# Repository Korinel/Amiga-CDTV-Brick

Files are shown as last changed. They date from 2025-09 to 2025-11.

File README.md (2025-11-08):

# The Commodore CDTV Brick 
## Two-player IR joystick interface

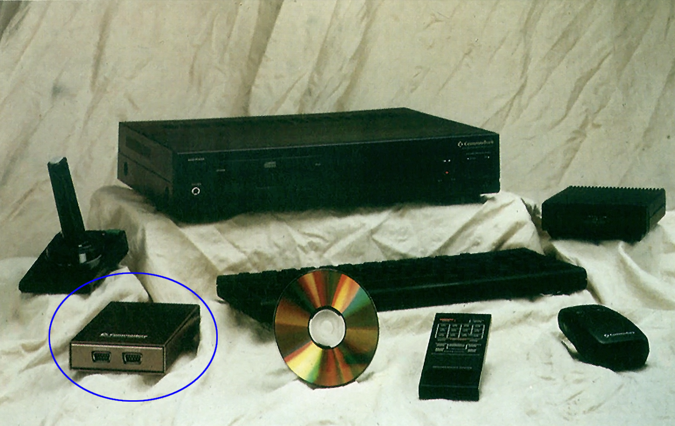
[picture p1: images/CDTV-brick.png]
Brick from CES

*The original Brick*

The circled **Commodore CDTV Brick** was a 1990s CDTV input device that sadly never made it to retail shelves. Instead, it appears that its functionality was integrated into the **Commodore CDTV CD1200** (below). The design of this Brick is entirely based on reverse engineering the protocols from the **CD1200 Trackball**, **CD1252/CD1253 mice**, **Brickette**, and the **CDTV Remote**.

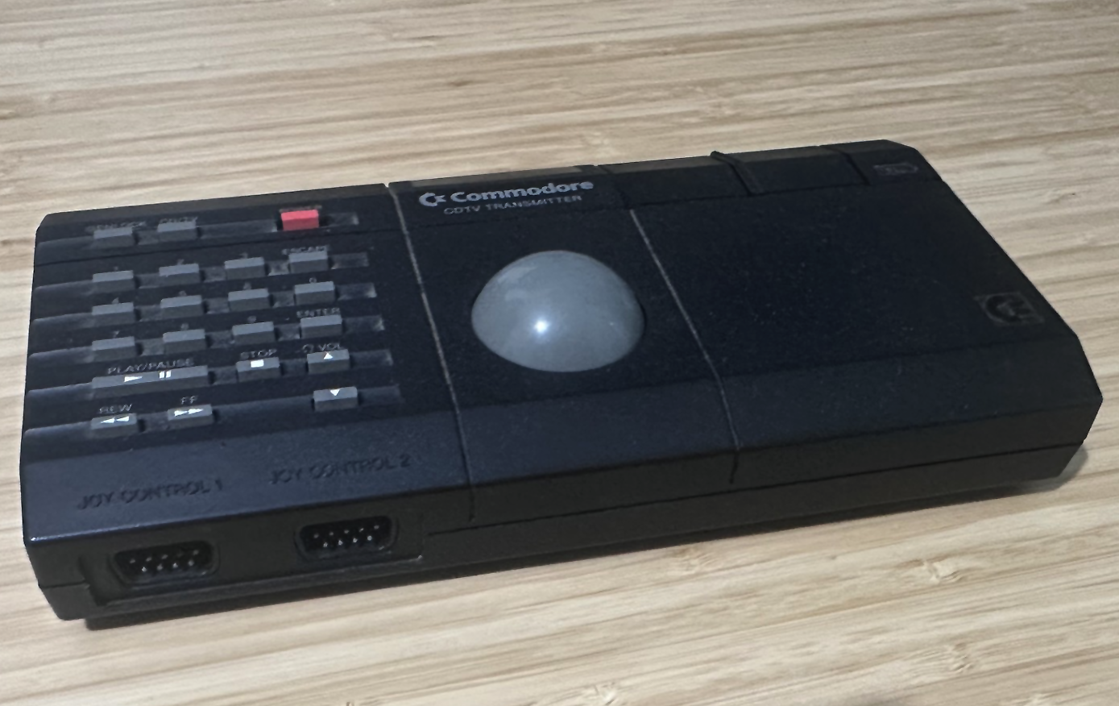
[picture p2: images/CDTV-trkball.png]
CD1200

*The CD1200, obtain via a mortgage!!*

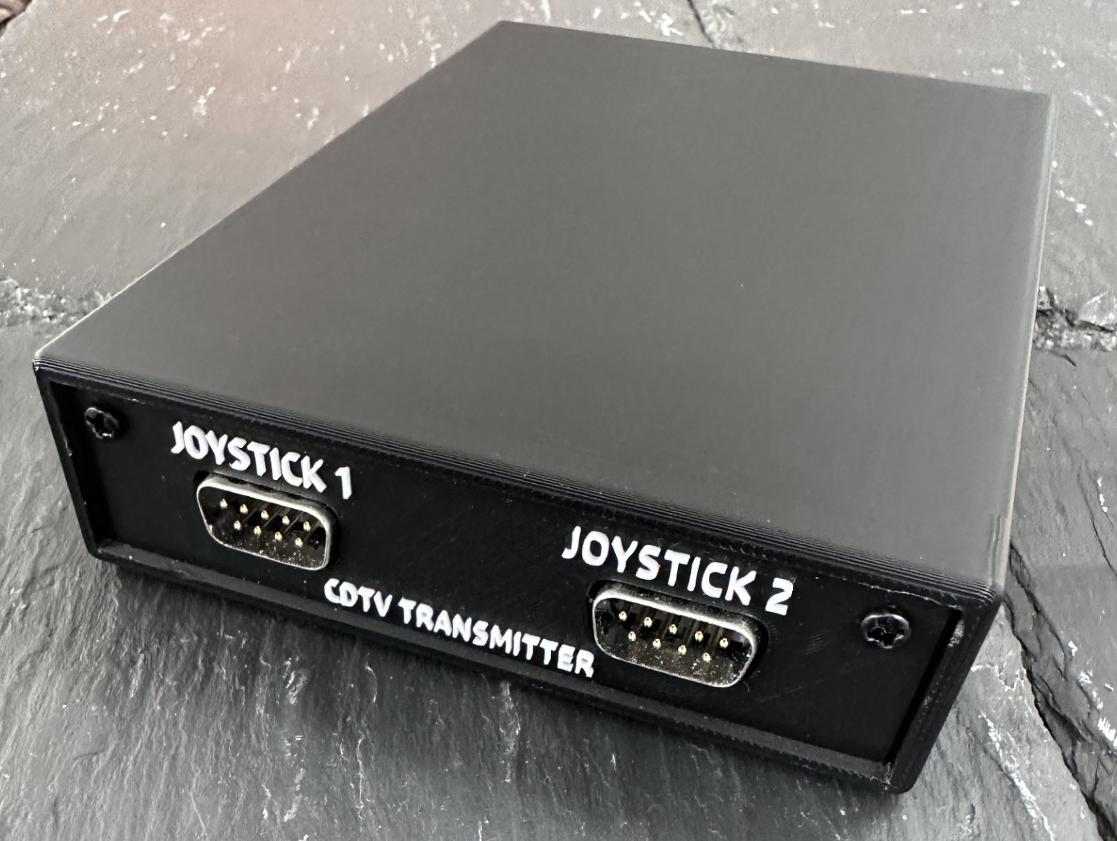
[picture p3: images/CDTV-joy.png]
CDTV Setup

*The Prototype Brick!*

## Project Overview
This  purpose of this project is to help makers design and build new devices, as the original retro mice, remote and trackerball command heavy prices second hand so there is an eager market for cheaper alternatives, without these input devices the CDTVs I fear will end up in landfill! 

The Pico project simply takes joystick input over GPIO, converts it to the IR protocol, and transmits it to an IR LED via a MOSFET. The code in this repro is for the Raspberry Pi Pico, both the RP2040 or newer RP2350 work fine. Visual Studio Code and the Offical Raspberry Pi Pico Extension were used to build the code. Everything is vanilla so should be easy enough to compile. The implementation is intentionally minimal for clarity, to enable ports to other MCUs, but there are known limitations:

1. **PWM vs PIO**: It may be preferable to use Pico PIO, as demonstrated in the [Pico IR example](https://github.com/raspberrypi/pico-examples/blob/master/pio/ir_nec/README.adoc).
2. **No defensive programming**: There is no error handling or debug output—failures may go unnoticed.
3. **Battery conservation**: No power-saving measures are implemented. The device does not stop timers or reduce CPU/PWM load during inactivity.

## Results!

The Brick performs exceptionally well, it enables **wireless two-player simultaneous Amiga gameplay**, testing on titles such as *Battle Squadron*, *SWIV*, *Project X*, *Zool*, and *Superfrog*—all played well without noticeable lag. More importantly, it avoids the need to open up the CDTV, remove chips, or pay upwards of **$1000 for a CD1200 Trackball**.

## Building Your Own

### PCB Manufacturing
The `KiCad` folder contains gerber files ready for PCB fabrication. Send these to your preferred manufacturer (JLCPCB, PCBWay, etc.), or use the schematic to build your own, the circuit is simple enough to prototype on a breadboard.

### 3D Printed Enclosure
3MF/STL files for the housing and faceplate are in the `3DPrint` folder. They're also available on [MakerWorld](https://makerworld.com/en/models/1804520-commodore-cdtv-2-joystick-ir-transmitter-enclosure).

### Firmware Installation
1. Install VSCode with the official Raspberry Pi Pico extension
2. Clone this repository
3. Build the project using the Pico SDK
4. Flash to your Pico via either:
   - USB mass storage mode (drag and drop the .uf2 file)
   - Debug probe using SWD pins

Good luck!

## Joystick Protocol

The joystick protocol appears to be *undocumented!* but here is the specification for use in your own devices:

- **Carrier frequency**: 40 kHz  
- **Duty cycle**: 33%

### Signal Encoding

Both mouse and joystick protocols use the same bit encoding:

| Bit | Mark (µs) | Space (µs) | Total (µs) |
|-----|---|---|---|
| 0 | 150 | 725 | 875 |
| 1 | 500 | 375 | 875 |

> All timing values should divide evenly by 25.

### Joystick Frame Structure

- **Header**: `1100` mark followed by `375` µs space  
- **Payload**: 25 bits total   
  - `1` flag for joystick (0 = joystick, 1 = mouse)  
  - `12` bits for two joystick inputs: (P1) F2, F1, R, L, D, U, (P2) F2, F1, R, L, D, U  
  - `12` bits for the inverse of the above, acting as a primitive check bit  
- **Footer**: `800` µs space (no specific footer signal)  
- **Frame duration**: ~24,150 µs (≈41 frames per second)  
- **Transitions per frame**: 52

When the user stops using the joystick, **four consecutive frames of all zeros** are sent. After that, the device ceases transmission, as there's little point repeatedly telling the CDTV that nothing is being pressed. This behaviour matches the CD1200 functionality.

## Brickette Protocol Comparison

The **Brickette** was a wired device similar to the CD1200 using a nearly identical joystick protocol with longer timings:

- **Header**: 1400 µs mark followed by 500 µs space  
- **Bit encoding**:

| Bit | Mark (µs) | Space (µs) | Total (µs) |
|-----|---|---|---|
| 0 | 150 | 1000 | 1150 |
| 1 | 650 | 500 | 1150 |

- **Frame duration**: ~32,000 µs (≈31 frames per second)

The Brickette is approximately **25% more latent** than the CD1200. This is likely because it transmits at the slower clock rate required for mouse support, which also operates at 31 frames per second. The Brickette also does **not** send the four “end of transmission” frames, leaving the CDTV unaware when the user stopped pressing joystick directions. This behaviour can be observed in **Amiga Test Kit**.

## Acknowledgements

This project was inspired by the excellent research and historical insights shared on [CDTV Land](https://cdtvland.com/2021/03/07/cdtv-brick-prototype/) regarding the elusive CDTV Brick prototype. 

---

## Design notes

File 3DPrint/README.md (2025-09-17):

# CDTV IR Transmitter – 3D-Printable Enclosure

This repository contains the 3D print files for the custom enclosure used in my **Commodore CDTV Dual-Joystick IR Transmitter** project.  
The design houses a Raspberry Pi Pico-based PCB, a 3×AA battery pack, dual DE-9 joystick connectors, and an IR LED driver.

You can also find it on MakerWorld https://makerworld.com/en/models/1804520-commodore-cdtv-2-joystick-ir-transmitter-enclosure

The original 1991 Brick design reminded me of an Amiga floppy drive, so I matched its general dimensions and appearance. This provided ample space for the components and added a satisfying heft.

---
Front panel with labelled joystick ports |

## Overview

The case was modelled in Fusion 360 and printed on a Bambu Lab P1S using PLA.  
It provides a snug, screw-together housing for the full PCB assembly, keeping the batteries secure while giving the DE-9 joystick ports a clean, retro look.

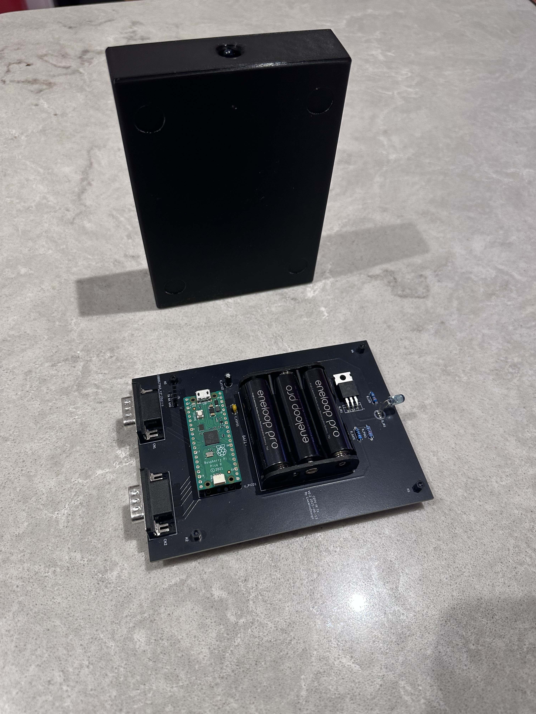
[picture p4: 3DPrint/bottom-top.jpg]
PCB with cover removed
 

# Bare Board Option
If you’d rather keep the board bare, you can simply fit nylon hex standoffs (sometimes called threaded spacers or PCB pillars) into the four mounting holes. These lightweight supports lift the PCB a few millimetres off the surface, preventing the solder joints or header pins from scratching furniture or shorting against anything conductive. Nylon is ideal because it’s non-conductive and won’t mark the desk, but brass or aluminium standoffs can also be used if you need extra rigidity. Just screw them in or use snap-fit pillars and the board will stay safely elevated without a full enclosure.

---

## Files Included

| File | Purpose |
|---|---|
| **CDTV-IR-Transmitter.step** | Full parametric CAD model for editing in Fusion 360, FreeCAD, or any STEP-compatible CAD package. |
| **CDTV-IR-Transmitter.3mf** | Ready-to-print Bambu Studio (3MF) project with recommended orientation and print settings. |
| **top-front.png** | Render/photo of the finished enclosure showing the labelled front panel. |
| **bottom-top.jpg** | Photo of the internal PCB and battery layout for reference. |
| **README.md** | This document. |

You can also download these files on [MakerWorld](https://makerworld.com/en/models/1804520-commodore-cdtv-2-joystick-ir-transmitter-enclosure).

---

## Printing Notes
- **Material:** PLA or PETG  
- **Layer Height:** 0.2 mm  
- **Infill:** 20% grid (or your preferred setting)  
- **Supports:** Not required if printed as supplied  
- **Fasteners:** 2 × M3×8 mm machine screws (for use with the optional heat-set inserts)

The STEP file allows easy editing if you wish to resize the case or change connector cut-outs.

---

## Assembly

1. Solder and fully test the PCB before assembly.  
2. Gently bend the IR LED so it aligns with the case opening, and—if needed—tilt the MOSFET for clearance.  
3. Slide the board along the internal runners, ensuring the IR LED sits correctly in the front hole and points straight ahead.  
4. (Optional) Heat-set two threaded inserts into the base mounting holes for a stronger screw joint.  
5. Fit the front face-plate and guide the DE-9 connectors neatly through their cut-outs.  
6. Attach the face plate, securing it with two screws to match your inserts.

---

## Possible Improvements
1. Add a side cut-out for USB (power) access to the Pico.  
   *Note: the Pico’s central placement makes convenient cable routing awkward.*  
2. Design a more robust power-switch mount.  
   *Bear in mind that extra holes or external switches may compromise the case’s clean look.*  
3. Refine the faceplate fit for easier removal so battery replacement is easier.  
   *It’s currently very snug and can stay in place without screws, but you need to tug the joysticks to remove it.*

Enjoy building your own CDTV IR Transmitter enclosure and feel free to remix or adapt the design!

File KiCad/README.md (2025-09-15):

# 📖 Electronics Design for the CDTV IR Joystick Controller

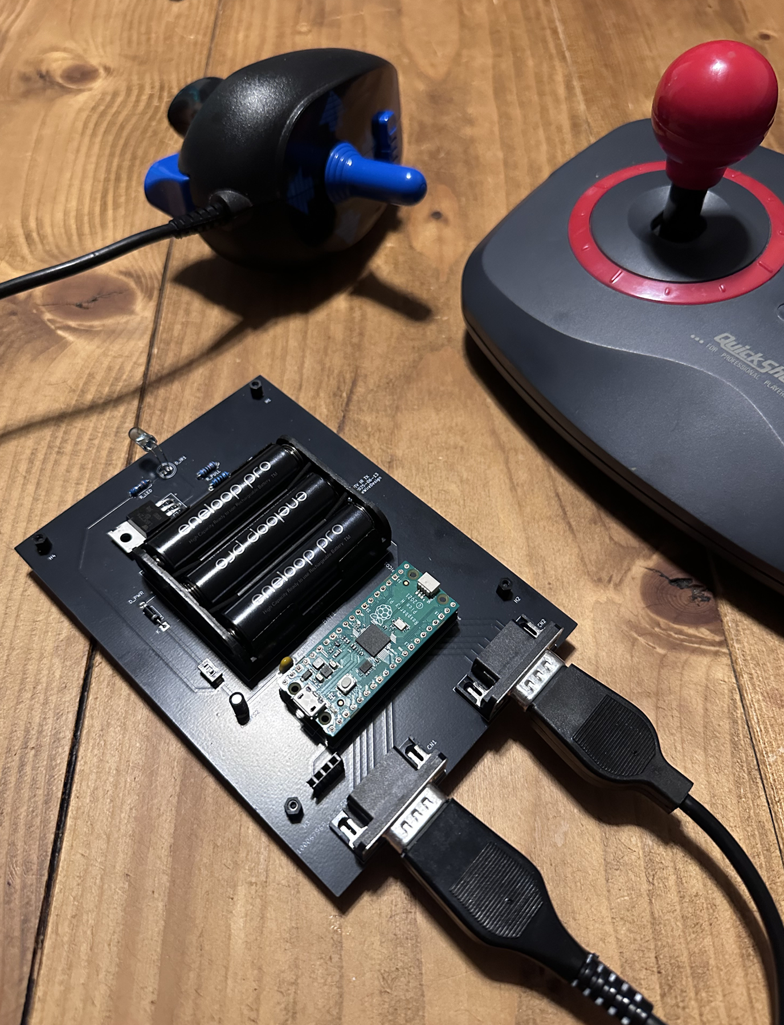
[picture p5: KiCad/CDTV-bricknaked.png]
CDTV IR Controller Schematic


> **N.B.** I am *not* an electrical engineer — I’m a software/reverse engineer by trade.  
> This project is a learning exercise, so there may be mistakes or sub-optimal choices.  
> The design was developed with the help of my good friend ChatGPT 🙂  

This README describes the **electronics design** for a modern replacement of the **Commodore CDTV infrared controllers**.  
It focuses on the hardware built around a **Raspberry Pi Pico (RP2040 or RP2350)** microcontroller, which reads two standard DE-9 joysticks and transmits their states to the CDTV via an **infrared LED driver circuit**.  

The README is organised into three main sections:  

- **🎮 Joystick Circuit** – how the DE-9 ports connect to the Pico, and why they are joystick-only.  
- **🔋 Power Circuit** – how batteries, diodes, and capacitors provide stable power for the Pico and LED.  
- **📡 IR LED Circuit** – how the MOSFET, resistors, and LED generate the CDTV-compatible IR output.  

Additional sections provide:  
- Technical notes on why mice cannot be used with these DE-9 connectors.  
- An overview of the **Amiga/CDTV mouse protocol** for reference.  
- Trade-offs between resistor values and LED current output for builders who want to tune brightness vs. battery life.  

👷 **Who is this for?**  
This README is written for **builders and electronics hobbyists** who want to reproduce, understand, or modify the CDTV IR controller hardware.  
It explains not just *what components are used*, but also *why they are there*, with calculations, alternatives, and practical design trade-offs.

---

## 🧰 Why Through-Hole Components?

This design deliberately uses **through-hole (THT) components** rather than surface-mount (SMD). 

The unit needs to be a little **heavy and bulky** so it doesn’t get dragged around by the joystick cables during frantic gameplay, helping it retain line-of-sight to the CDTV’s IR receiver. 

### Reasons for Through-Hole
- **Large mechanical parts**:  
  - The **battery holder**, **IR LED**, and **DE-9 joystick connectors** are inherently large and designed as through-hole parts.  
  - The **Raspberry Pi Pico module** itself is also a through-hole DIP board.  
  - These parts set the minimum size of the PCB — it will never be a tiny design.  
- **Ease of assembly**:  
  - Through-hole parts are much easier to solder by hand, making this build accessible to hobbyists with basic tools.  
  - Component orientation is clear, and mechanical strength is higher for connectors and switches that will see stress.  
- **Component availability**:  
  - THT resistors, diodes, capacitors, and headers are cheap and widely available.  
  - Builders can source them from almost any electronics supplier or salvage them from donor boards.  

### Could this be SMD?
Swapping to SMD would reduce board size **only for the passives** (resistors, capacitors, pull-ups).  
However:  
- **Battery holders, LEDs, DE-9 connectors, and the Pico** remain large and through-hole.  
- The actual PCB reduction would be modest because the layout must still accommodate these large footprints.  
- SMD would complicate soldering for beginners and make the design harder to reproduce at home.  

---

## 📐 Schematic

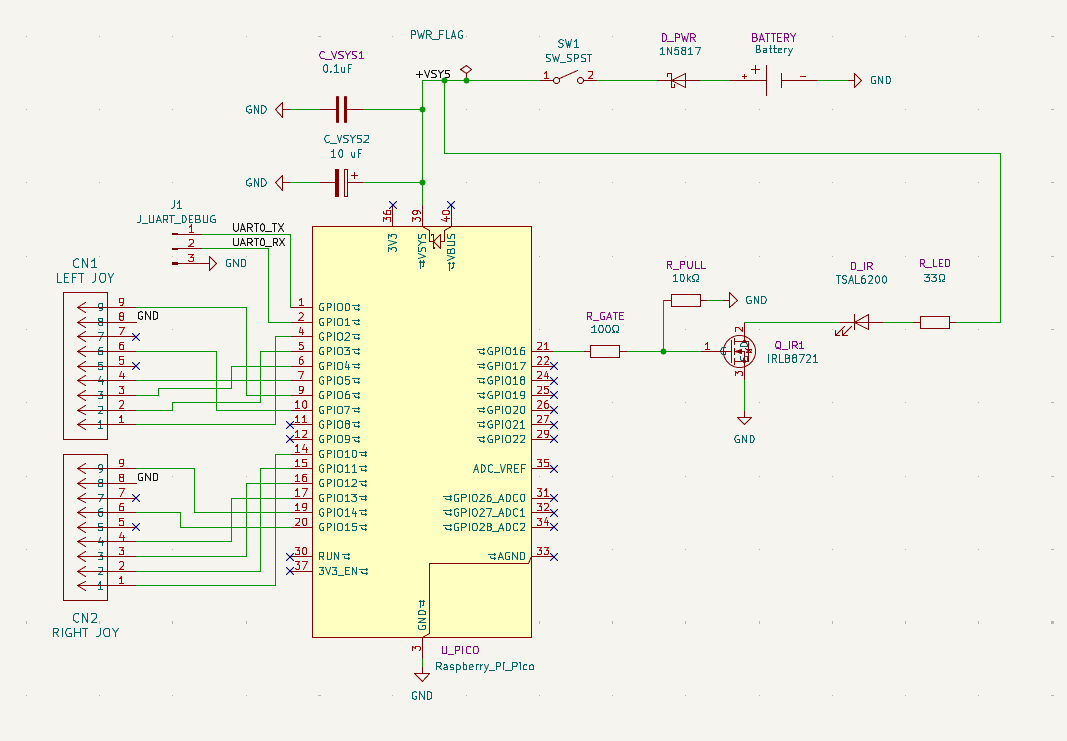
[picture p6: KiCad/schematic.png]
CDTV IR Controller Schematic


---

## 🎮 Joystick Circuit

All joystick ground pins (CN1/CN2), battery negative, and Pico GND must share the same reference. VSYS after the Schottky diode is the main supply rail for both the Pico and the IR LED driver circuit.

| Component | Purpose in Design | Reason | Alternative Options |
|---|---|---|---|
| **U_PICO1 Raspberry Pi Pico** | Main microcontroller (RP2040 or RP2350) that reads joystick inputs and encodes them for IR transmission. All joystick lines are pulled to GND when active, and read as logic LOW by the Pico. VSYS powers the board and sets the logic level reference. | Cheap, widely available, powerful enough for real-time IR modulation. Plenty of GPIO pins for two DE-9 ports. | Arduino Nano/Pro Mini (requires redesign for I/O mapping), STM32 “Blue Pill”. |
| **CN1 / CN2 (DE-9 connectors)** | Standard joystick connectors (Atari/Amiga compatible). Each pin corresponds to joystick direction or fire buttons. Internally wired to Pico GPIO, with common GND pins tied to system GND. **Pin 5 (potentiometer X)** and **Pin 7 (+5 V supply)** are unused. | DE-9 is the Amiga standard, ensures physical compatibility. Right-angle THT sockets are robust for repeated plug/unplug cycles. | Any through-hole DE-9 connector (straight or right-angle). Panel-mount DE-9 with short wires for mechanical flexibility. |

### Notes on Unused Pins
- **Pin 5 (Pot X / analogue input)** – On the original Amiga this is used for analogue paddles or light pens. This design is digital-only, so the pin is left unconnected.  
- **Pin 7 (+5 V supply)** – Provides +5 V to mice and other powered peripherals. Since this board does not support mice and is battery-powered, +5 V is not provided to avoid backfeeding or damaging the Pico.  

### DE-9 Joystick Pinout (per port)

| DE-9 Pin | Function | Pico GPIO |
|---|---|---|
| 1 | Up | GP2 / GP10 |
| 2 | Down | GP3 / GP11 |
| 3 | Left | GP4 / GP12 |
| 4 | Right | GP5 / GP13 |
| 6 | Fire 1 | GP7 / GP15 |
| 9 | Fire 2 | GP6 / GP14 |
| 8 | GND | GND |
| 5, 7 | NC/+5V | Not used |

### ⚠️ Autofire

Autofire is unreliable here (as it was on the original CD1200). Classic autofire works with a direct digital connection and is powered from +5 V on Pin 7.  In this design the Pico must clock and convert joystick inputs into a serial IR stream, so the rapid autofire pulses cannot be transmitted reliably.

---

## 🔋 Power Circuit

All joystick ground pins (CN1/CN2), battery negative, and Pico GND must share the same reference. VSYS after the Schottky diode is the main supply rail for both the Pico and the IR LED driver circuit.

| Component | Purpose in Design | Reason| Alternative Options |
|---|---|---|---|
| **BAT1 (Battery holder)** | Provides portable AA battery supply | 3 × AA is the Pico’s standard input range (VSYS). Delivers ~3.6 V with NiMH and ~4.5 V with Alkaline. After the Schottky diode drop this becomes ~3.25 V (NiMH) or ~4.15 V (Alkaline), which is ideal for the IR LED drive calculations. | Li-ion 18650 3.7 V cell with protection + charging circuit (but requires regulator for safe Pico supply). |
| **D_PWR1 1N5817 (Schottky diode)** | Reverse-current protection and source OR-ing between USB and battery. Prevents backfeeding into the batteries when USB is plugged in. | Very low forward drop (0.2–0.4 V), preserving as much voltage as possible for the LED. Rated for >1 A, so well above the 100 mA load. | 1N5819 (slightly higher drop), SS14 (SMD equivalent). |
| **C_VSYS1 0.1 µF ceramic capacitor** | Local high-frequency decoupling at the Pico VSYS pin. Suppresses fast transients from the IR LED switching and keeps supply stable at the microsecond scale. | Small MLCCs have very low ESR and respond quickly. This value is a “standard bypass” close to the IC. | 0.47 µF or 1 µF ceramic (improves HF filtering further). |
| **C_VSYS2 10 µF electrolytic capacitor** | Bulk smoothing capacitor. Handles lower-frequency voltage dips caused by the IR LED pulsing at 40 kHz. | 10 µF provides enough charge reservoir to stop Pico resets during bursts. Electrolytic tolerates ripple current better than ceramic alone. | 22 µF or 47 µF for longer battery leads or higher burst currents. |
| **SW1 SPST switch** | Physical battery isolation. Breaks connection between the pack and the diode, allowing complete shutdown without USB unplugging. | Slide switches are compact, tactile, and easy to panel-mount. Current rating is comfortably above draw. | Rocker switch (more robust), latching push-button. |

---

## 📡 IR LED Circuit

The IR LED is driven at 40 kHz with a duty cycle <50%, so the average current is well below the peak. This allows safe operation even when instantaneous current approaches the LED’s maximum continuous rating.

| Component | Purpose in Design | Reason | Alternative Options |
|---|---|---|---|
| **D_IR1 TSAL6200 IR LED** | The main emitter. A high-power 940 nm IR LED that converts current pulses into IR light detectable by the CDTV receiver. Forward voltage ~1.35 V at 100 mA, with a 200 mA peak rating. | Wide angle (±20°), high radiant intensity, and spectral match to standard IR demodulators. Handles short current bursts without thermal runaway. | TSAL4400 (narrower 10° beam, longer range), SFH4546 (high-power emitter). |
| **Q_IR1 IRLB8721 (MOSFET)** | Low-side switch for the LED. Takes PWM drive from the Pico and switches LED current through R_LED1. Its low Rds(on) (<20 mΩ) ensures almost no voltage drop, so current is defined by the resistor not the MOSFET. | Logic-level gate threshold (<2 V), meaning it fully enhances with Pico’s 3.3 V output. Robust current handling (tens of amps), way above the sub-0.1 A required here. | IRLZ34N (similar spec, slightly higher Rds(on)), AO3400 (SMD, low gate charge). |
| **R_LED1 33 Ω resistor** | Series current-limiting resistor. Ensures the LED does not exceed its safe forward current by dropping the excess supply voltage. At ~4.15 V (alkaline supply after Schottky drop), current ≈ (4.15 V − 1.35 V)/33 Ω ≈ 85 mA. | Provides reliable current limiting independent of battery type. Keeps LED near 100 mA continuous spec but well under 200 mA pulsed limit. Dissipation ≈ 0.24 W at full current, so a 0.25 W or 0.5 W resistor is appropriate. | 27 Ω (≈100 mA, brighter but hotter), 39 Ω (≈70 mA, dimmer but saves battery). |
| **R_PULL1 10 kΩ** | Gate pull-down resistor. Holds MOSFET gate at 0 V when Pico GPIO is in reset, boot, or high-impedance state. Without it, the gate capacitance could float high and partially turn on the MOSFET, causing LED ghost flicker. | 10 kΩ provides a defined low with negligible current draw from the Pico. Value is not critical—just needs to bleed off gate charge slowly. | 4.7 kΩ (stronger pull-down, faster discharge), 22 kΩ (weaker pull, less leakage). |
| **R_GATE1 100 Ω resistor** | Gate series resistor. Sits between Pico GPIO and MOSFET gate to limit instantaneous charging/discharging current into the gate capacitance (~1 nF). Prevents ringing, reduces EMI, and protects the GPIO driver. | 100 Ω gives a good compromise: Pico can still switch gate fast enough for 40 kHz IR PWM, but without dumping tens of mA into the GPIO pin. | 68 Ω (faster switching, slightly more stress), 220 Ω (slower switching, lower stress). |

## 🔢 IR LED Resistor Trade-offs

| Resistor | Supply | I_LED (mA) | P_R (mW) | P_LED (mW) |
|---|---|---|---|---|
| 27 Ω | Alkaline | 103.7 | 290.4 | 140.0 |
| 27 Ω | NiMH | 70.4 | 133.7 | 95.0 |
| 33 Ω | Alkaline | 84.8 | 237.6 | 114.5 |
| 33 Ω | NiMH | 57.6 | 109.4 | 77.7 |
| 39 Ω | Alkaline | 71.8 | 201.0 | 96.9 |
| 39 Ω | NiMH | 48.7 | 92.6 | 65.8 |

---

## 🛠️ Debug / Programming Header

| Component | Purpose in Design | Reason | Alternative Options |
|---|---|---|---|
| **J1 (3-pin header)** | Breaks out the Pico’s UART for debugging or programming. | Provides a serial console during development, useful for logging joystick states or IR timing. Simple 3-pin header keeps it compact. | Any 3-pin 2.54 mm header. Could also break out full SWD (3 or 5-pin) for low-level debugging. |

### Pinout (J1)
| Pin | Signal | Notes |
|-----|---|---|
| 1 | GND | Common ground reference |
| 2 | TX | Pico TX (connect to RX of USB–UART adapter) |
| 3 | RX | Pico RX (connect to TX of USB–UART adapter) |

⚠️ **Note for builders**:  
- This header is optional if you only intend to flash `.uf2` files via USB.  
- It is strongly recommended during early development or troubleshooting IR timings.  
- Keep the ground pin connected whenever using an external UART adapter to avoid floating reference issues.

---

## 🖱️ Amiga / CDTV Mouse Protocol (and why it is not supported here)

It is important to understand that although Amiga/CDTV joysticks and mice share the same DE-9 connector format, the **signals and requirements are completely different**.

- A **joystick** is just a set of switches. Each direction or fire button shorts its pin to GND when pressed. The Pico can read these directly as active-low digital inputs.  
- An **Amiga mouse** is not switch-based. It uses two quadrature encoders that continuously generate pulse trains on the direction pins as the ball moves. These need to be sampled and decoded in real time.  
- The mouse also expects a **+5 V supply** on Pin 7 of the DE-9 to power its encoders. This design deliberately does not supply 5 V, because it is joystick-only.

### Important clarification  
The **Commodore CD1200 trackball** (the inspiration for this project) also **did not present mouse signals** on its DE-9 ports. Those pins were never wired for mouse use. Instead:  
- The **trackball** in the CD1200 produced its own data stream.  
- That stream used a variation of the **CDTV IR mouse protocol** (serial, not quadrature).  
- Mouse support in the CDTV therefore came from the **dedicated IR mouse (CD-1252) and wired mouse (CD-1253)**, not from the DE-9 joystick sockets.  

### Why mice are not supported here (YET!)
This project replicates the CD1200’s joystick behaviour, not the IR mouse. Supporting mice would require:  
- Supplying +5 V on Pin 7.  
- Capturing and decoding quadrature pulses at high speed.  
- Translating movement into the CDTV’s proprietary IR mouse serial protocol.  

Since the original CD1200 never offered mouse inputs on its DE-9 ports, this design remains **joystick-only** — just like the original hardware.

---

## 📡 CDTV Mouse Serial Protocol

For builders who want to experiment with adding mouse support, here are the key details of the **CDTV mouse protocol** (used by CD-1252 IR and CD-1253 wired mice):

The CDTV mouse (CD-1252 IR / CD-1253 wired) uses a proprietary asynchronous serial protocol.  

- **Frame structure**:  
  - **Start bit**: 1100 µs low pulse, 375 µs high.  
  - **19 data bits**: transmitted MSB first.  
  - **Stop bit**: 100 µs line held low.  

- **Bit encoding** (each bit = ~875 µs total):  
  - **0** = ~500 µs low, ~375 µs high.  
  - **1** = ~150 µs low, ~725 µs high.  

- **Contents of the 19 data bits**:  
  - **Mouse flag** (always `1` to indicate mouse device).  
  - **Button states**: `left` and `right` button down/up.  
  - **X movement**: `8` bit signed value.  
  - **Y movement**: `8` bit signed value.  

- **Timing**:  
  - Packets sent every ~32 ms while the mouse is moving.  
  - There is a ~14 ms gap between frames.  
  - Idle state is a steady HIGH level.  

---
## 🔚 Next Steps

With the electronics design understood, builders can:

1. **Assemble the PCB** – start with resistors and small passives, then add connectors, the Pico, and finally the battery holder and IR LED.  
2. **Build your image** – see the `root` directory for Pico source code.  
3. **Test the IR output** – confirm joystick presses translate into IR frames using a Amiga Test Kit or an oscilloscope.  
4. **Enclose the build** – use the provided 3D-printed case files to house the PCB, ensuring the IR LED has clear line-of-sight to the CDTV receiver.  

This README covers the **hardware design**. For the **firmware details**, please refer to the dedicated firmware documentation in the directory above.

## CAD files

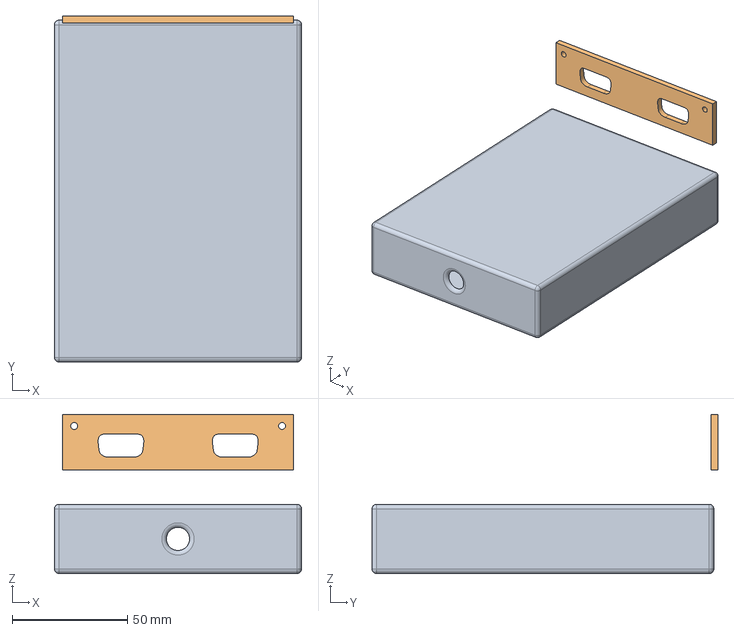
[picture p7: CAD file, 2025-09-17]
3DPrint/CDTV-IR-Transmitter.step
107.0 x 149.8 x 68.9 mm

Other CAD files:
3DPrint/CDTV-IR-Transmitter.3mf

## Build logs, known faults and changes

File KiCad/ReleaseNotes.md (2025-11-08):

# CDTV IR Controller - Release Notes

## Version 0.3
**Release Date:** [2025-11-08]

### Bug Fixes
- **Critical Fix: IR LED Polarity Correction**
  - Corrected IR LED (TSAL6200) orientation in both KiCad schematic symbol and PCB footprint
  - The LED symbol was incorrectly drawn with anode and cathode reversed, causing the component to be installed backwards
  - PCB now matches the TSAL6200 datasheet pinout (Pin 1 = Cathode, Pin 2 = Anode)
  - **Impact:** Previous versions (v0.1 and v0.2) required the IR LED to be installed with reversed polarity to function correctly. Version 0.3 allows correct installation following component markings (flat edge = cathode)

### Acknowledgements
Special thanks to **chrisblown** and **youenchene** for identifying and reporting this critical polarity issue! 

---

## Version 0.2
**Release Date:** [2025-07-18]

### Features Added
- **SW1 Power Switch:** Added a power switch to save on battery power
- **Pico Debug Header:** Exposed TX, RX, and GND pins on Raspberry Pi Pico for serial debugging and programming access

---

## Version 0.1
**Release Date:** [2025-05-15]

### Initial Release
- Original CDTV IR Controller design
- Raspberry Pi Pico-based IR transmitter
- TSAL6200 IR LED with IRLB8721 MOSFET driver circuit
- Basic power management circuitry

---

## Migration Notes

### Upgrading from v0.1 or v0.2 to v0.3
If you have already built a board using v0.1 or v0.2 gerbers:
- Your board will continue to work with the IR LED installed in reverse (opposite to component markings)
- No hardware modifications are required for existing boards
- Future builds using v0.3 gerbers should install the LED following standard component markings (flat edge toward MOSFET)

### Assembly Notes for v0.3
- Install TSAL6200 IR LED with the **flat edge of the dome toward the MOSFET** (cathode side)
- The square pad connects to the cathode (flat edge side)
- The round pad connects to the anode (round edge side)

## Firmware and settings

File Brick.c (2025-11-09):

// =============================================================================
/*
 * Brick - CDTV Joystick to IR Transmitter
 * Copyright (c) 2025 Korinel
 * SPDX-License-Identifier: MIT
 */
// =============================================================================

#include "pico/stdlib.h"     // gpio, sleep_ms, stdio_init_all, panic
#include "pico/time.h"       // repeating_timer_t, add_repeating_timer_us
#include "hardware/clocks.h" // clock_get_hz, clk_sys
#include "hardware/pwm.h"    // pwm APIs
#include "hardware/sync.h"   // __wfi()
#include <stdint.h>          // fixed-width integer types

// =============================================================================
// GPIO Pin Definitions
// =============================================================================

// GPIO Input Pin Definitions (Active LOW inputs)
#define JOY1_UP 2
#define JOY1_DOWN 3
#define JOY1_LEFT 4
#define JOY1_RIGHT 5
#define JOY1_FIRE2 6
#define JOY1_FIRE1 7

#define JOY2_UP 10
#define JOY2_DOWN 11
#define JOY2_LEFT 12
#define JOY2_RIGHT 13
#define JOY2_FIRE2 14
#define JOY2_FIRE1 15

// GPIO Output Pin Definitions (Active HIGH outputs)
#define LED_IR 16
#define LED_PICO 25

// =============================================================================
// IR Protocol Definitions
// =============================================================================

static const uint32_t ir_frequency_hz = 40000;          // 40 kHz carrier = 25us period
static const uint8_t ir_duty_cycle_percent = 33;        // 33% duty (CD1252 mouse is 33% too)
static const uint16_t data_mask = 0x0FFF;               // 12 bits valid data

/* CDTV IR joystick protocol timings (microseconds) */
static const uint32_t ir_hdr_mark_us = 1100;            // 44 * 25us
static const uint32_t ir_hdr_space_us = 375;            // 15 * 25us
static const uint32_t ir_zero_mark_us = 150;            //  6 * 25us
static const uint32_t ir_zero_space_us = 725;           // 29 * 25us
static const uint32_t ir_one_mark_us = 500;             // 20 * 25us
static const uint32_t ir_one_space_us = 375;            // 15 * 25us                
static const uint32_t ir_interframe_gap_us = 800;       // 32 * 25us

// =============================================================================
// GPIO and state definitions
// =============================================================================
// Read joystick GPIO pins in CDTV defined order
static const uint8_t gpio_pins[] = {
    JOY2_UP, JOY2_DOWN, JOY2_LEFT, JOY2_RIGHT, JOY2_FIRE1, JOY2_FIRE2,
    JOY1_UP, JOY1_DOWN, JOY1_LEFT, JOY1_RIGHT, JOY1_FIRE1, JOY1_FIRE2
   };

static const size_t num_gpio_pins = sizeof(gpio_pins) / sizeof(gpio_pins[0]);

// PWM state
static uint32_t pwm_slice_num = 0;
static uint32_t pwm_channel = 0;
static uint16_t pwm_level = 0;

// ISR / timer state
static volatile bool frame_pending = false; // set by timer IRQ, cleared in main loop
static const uint32_t max_idle_frames = 4;  // consecutive idle frames 
static uint32_t idle_frame_count = 0;       // counts consecutive idle frames

// Frame length in microseconds = ~24150 us
static const uint64_t ir_frame_period_us =
    (int64_t)ir_hdr_mark_us + ir_hdr_space_us +
    (13LL * (ir_zero_mark_us + ir_zero_space_us)) +
    (12LL * (ir_one_mark_us + ir_one_space_us)) +
    ir_interframe_gap_us;

static repeating_timer_t frame_timer; // frame timer handle

// =============================================================================
// Initialization
// =============================================================================
static void init_gpio(void)
{
    // Configure joystick inputs as pulled-up (active LOW)
    for (size_t i = 0; i < num_gpio_pins; ++i)
    {
        int pin = gpio_pins[i];
        gpio_init(pin);
        gpio_set_dir(pin, GPIO_IN);
        gpio_pull_up(pin);
    }

    // Configure LED for feedback
    gpio_init(LED_PICO);
    gpio_set_dir(LED_PICO, GPIO_OUT);
    gpio_put(LED_PICO, 0);
}

static void init_pwm_for_ir(void)
{
    // configure pin for PWM and capture slice/channel
    gpio_set_function(LED_IR, GPIO_FUNC_PWM);
    pwm_slice_num = pwm_gpio_to_slice_num(LED_IR);
    pwm_channel = pwm_gpio_to_channel(LED_IR);

    // compute wrap (ticks per carrier period) and duty in ticks
    uint32_t sys_clk_freq = clock_get_hz(clk_sys);

    uint16_t pwm_wrap = (uint16_t)((sys_clk_freq / (ir_frequency_hz)) - 1);
    pwm_level = (pwm_wrap * ir_duty_cycle_percent) / 100; // IR_DUTY_CYCLE is the percentage

    // initialise PWM with required wrap and start it, keep output off
    pwm_config config = pwm_get_default_config();
    pwm_config_set_wrap(&config, pwm_wrap);

    pwm_init(pwm_slice_num, &config, true);
    pwm_set_chan_level(pwm_slice_num, pwm_channel, 0);
}

// =============================================================================
// IR transmission logic
// =============================================================================
static inline void ir_emit(uint32_t mark_us, uint32_t space_us)
{
    // Turn carrier on for mark_us then off for space_us using PWM level
    pwm_set_chan_level(pwm_slice_num, pwm_channel, pwm_level);
    busy_wait_us_32(mark_us);

    pwm_set_chan_level(pwm_slice_num, pwm_channel, 0);
    busy_wait_us_32(space_us);
}

static void transmit_cdtv_frame(uint16_t joy_data)
{
    // Ensure only the lower 12 bits are used
    uint16_t check_bits = (uint16_t)(~joy_data) & data_mask;

    // Header
    ir_emit(ir_hdr_mark_us, ir_hdr_space_us);

    // Joystick identifier bit (0)
    ir_emit(ir_zero_mark_us, ir_zero_space_us);

    // Send 12 data bits (MSB first)
    for (size_t i = num_gpio_pins; i-- > 0;)
    {
        if (joy_data & (1u << (unsigned)i))
            ir_emit(ir_one_mark_us, ir_one_space_us);
        else
            ir_emit(ir_zero_mark_us, ir_zero_space_us);
    }

    // Send 12 inverted check bits (MSB first)
    for (size_t i = num_gpio_pins; i-- > 0;)
    {
        if (check_bits & (1u << (unsigned)i))
            ir_emit(ir_one_mark_us, ir_one_space_us);
        else
            ir_emit(ir_zero_mark_us, ir_zero_space_us);
    }

    // carrier already off; inter-frame gap is provided by the repeating timer
    // so do not send the footer here.
}

// =============================================================================
// Joystick input reading
// =============================================================================
static inline uint16_t read_joystick_inputs(void)
{
    uint16_t joystick_bits = 0;

    // Snapshot all GPIO inputs once (SIO->GPIO_IN), invert because inputs are active LOW
    uint32_t all_gpio_state = ~gpio_get_all();
    for (size_t i = 0; i < num_gpio_pins; ++i)
    {
        if (all_gpio_state & (1u << gpio_pins[i]))
            joystick_bits |= 1u << i;
    }
    return joystick_bits;
}

// =============================================================================
// Callbacks
// =============================================================================
static bool frame_timer_callback(repeating_timer_t *t)
{
    (void)t;
    frame_pending = true;
    return true;
}

// =============================================================================
// Main - Entry point
// =============================================================================
int main(void)
{
    init_gpio();
    init_pwm_for_ir();

    // Start repeating frame timer and check success
    if (!add_repeating_timer_us(-ir_frame_period_us, frame_timer_callback, NULL, &frame_timer))
    {
        panic("Failed to initialize frame timer");
    }

    // Flash LED to show initialization
    gpio_put(LED_PICO, 1);
    sleep_ms(500);
    gpio_put(LED_PICO, 0);

    while (true)
    {
        __wfi(); // wait for timer tick / IRQ

        if (frame_pending)
        {
            frame_pending = false;

            uint16_t joy_data = read_joystick_inputs();

            if (joy_data == 0)
            {
                ++idle_frame_count;
            }
            else
            {
                idle_frame_count = 0;
            }

            // if idle_threshold is reached do NOT transmit further idle frames
            if (idle_frame_count < max_idle_frames)
            {
                transmit_cdtv_frame(joy_data);
            }
        }
    }
}
// =============================================================================
// END OF FILE
// =============================================================================

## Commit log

2025-09-14 Replace .gitignore with updated version for Pico C project
    [Brick.c]
2025-09-15 Updated link to Schematic
2025-09-15 Added KiCad/CDTV-bricknaked.png and updated KiCad/README.md
2025-09-15 Removed lines from KiCad/README.md
2025-09-17 Added Added 3D Print files
    [CDTV-IR-Transmitter.3mf, CDTV-IR-Transmitter.step]
2025-11-08 Release v0.3: Updated schematic and Gerbers
2025-11-08 Release v0.3: Updated schematic
2025-11-09 Reordered joystick GPIO pin definitions and updated board type in CMakeLists.txt
